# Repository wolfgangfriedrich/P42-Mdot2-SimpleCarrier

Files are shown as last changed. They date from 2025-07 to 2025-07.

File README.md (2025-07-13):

A carrier to connect to a M.2 2230/3030 or 2242/3042 Board through USB, UART or I2C. All other signals are broken out to to TH testpoints.

List of features:

    M.2 slot with all pads on the board to accept any key slot M.2 module, if the correct connector is mounted.
    Specifically made for A key and E key, targeting WiFi, Bluetooth, WWAN adapter.
    Works with a subset of signals for B key and M key, but not as a USB memory interface for SSDs.
    All signals available on through hole test points on a 2.54mm (0.1") grid.
    PCIe signals are routed as differential pairs.
    USB-C set up for 5V 3A max power draw.
    Switching regulator to generate 3.3V 1.5A to power the M.2 module.
    1.8V LDO regulator to be able to work with the 1.8V UART and I2C signals.
    Power switch for the 3.3V to the M.2 module with an enable jumper and 500mA over-current protection.
    LEDs for 1.8V, 3.3V and switched 3.3V; LED for over-current condition.
    4 mounting holes.
    Mounting holes for nuts to secure 2230 or 2242 modules.
    Level shifter and connector to make UART accessible on a 3-pin header.
    Level shifter and QWIIC connector to make I2C accessible on a 3-pin header.
    Extra testpoints for GND, VBUS, 3.3V, 1.8V
    Design in KiCAD.

The design came to life initially to test my M.2 RP2350 board (https://www.tindie.com/products/pier42/pico2-m2). I needed a test platform to access all signals of the M.2 interface with E or A key. Single Board Computers with a M.2 port often don't access all pins, so I built this board and think it is very useful.

M.2 carrier boards are generally for B or M key SSDs to other internal interfaces. I am not aware of any breakout board for M.2 modules with enhanced functionality. There are a few passive breakout boards available that simply connect all pins to standard headers.

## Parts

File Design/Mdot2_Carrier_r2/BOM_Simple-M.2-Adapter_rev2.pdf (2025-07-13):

# | Reference | Qty Value | Description | DNP JLCPCB # LCSC Part #Mfr | Mfr PN | Mfr1 | Mfr1 PN | Mfr2 | Mfr2 PN

1 | C1 | 1 10n | CAP CER 10NF 10% 50V X7R 0603 | C57112 | C57112 | generic | na | generic | na
2 | C2,C6,C10,C11 | 4 2.2u | CAP CER 2.2UF 16V X5R 0603 | C23630 | C23630 | generic | na | generic | na
3 | C3,C4 | 2 10u | CAP CER 10UF 50V X7R 1206 | C13585 | C13585 | Samsung CL31B106KBHNNNE | Samsung | CL31B106KBHNNNE
4 | C5,C9,C12,C13 | 4 100nF | Cap Cer, 100nF, +-10%, X7R, 50V, 0603 | C14663 | C14663 | generic | na | generic | na
5 | C7,C8 | 2 4.7u | CAP CER 4.7UF 50V X5R 0805 | C98192 | C98192 | Murata | GRT21BR61H475KE13L Samsung | CL21A475KBQNNNE | Murata | GRT21BR61H475KE13L
6 | D1,D3 | 2 Yellow | LED YELLOW CLEAR 0603 SMD | C434424 C434424 | WÃ¼rth | 150060YS75000 | Yongyu Photoelectric | SZYY0603Y
7 | D2 | 1 Green | LED GREEN CLEAR 0603 SMD | C434420 C434420 | WÃ¼rth | 150060GS75000 | Yongyu Photoelectric | SZYY0603G
8 | D4 | 1 Red | LED RED CLEAR 0603 SMD | C2286 | C2286 | | WÃ¼rth | 150060RS75000 | Hubei KENTO Elec | KT-0603R
9 | D5 | 1 DSS26 | TVS DIODE 12.8VWM 21.2VC SOD123 | C511867 C511867 On Semi | SS26FL | On Semi | SS26FL | BORN | DSS26
10 | FB1,FB2 | 2 600R/0.5A | IND FERRITE 600R 0.5A 0603 | C710380 C710380 Murata | BLM18AG601SN1D | Murata | BLM18AG601SN1D
11 | J1 | 1 Bus_M.2 | M.2 Socket 1-SD Mechanical Key AE | C2761457 FOXCONN AS0BC21-S48BE-7H | Amphenol ICC (FCI) MDT420E01001 | Amphenol ICC (FCI) | MDT420E03001
12 | J2 | 1 USB_C | CONN, USB-C 2.0, TH | C2988369 G-Switch GT-USB-7010ASV | G-Switch | GT-USB-7010ASV
13 | J3 | 1 ENABLE | CONN, 2PIN, 2.54MM, TH | C492401 C492401 Adam TechPH1-02-UA | Adam Tech | PH1-02-UA
14 | J4 | 1 QWIIC | CONN HEADER R/A 4POS 1MM SMD | C160404 C160404 JST | SH_SM04B-SRSS-TB | JST | SM04B-SRSS-TB(LF)(SN)
15 | J5 | 1 UART | CONN, 3PIN, 2.54MM, TH | C49257 | C49257 | Adam TechPH1-03-UA
16 | L1 | 1 4.7uH | FIXED IND 4.7UH 3A 37MOHM SMD | C171792 C171792 Murata | LQH5BPN4R7NT0L | Murata | LQH5BPN4R7NT0L | TDK | VLS6045AF-6R8M
17 | Q1 | 1 FDN304P | MOSFET P-CH 20V 2.4A 53mOhm, SOT23-3 | DNP | C154510 | ON Semi | FDN306P
18 | Q2 | 1 FDC6303N | MOSFET 2N-CH 25V 0.68A SOT23-6 G1S2G2D2S1D1 | C5246389 C5246389 Rohm | FDC6303N | TECH PUBLIC FDC6301N-TP
19 | R1,R7,R11 | 3 27R | RES 27R 1% 0.1W 0603 | C25190 | C25190 | generic | na | generic | na
20 | R2,R5,R6,R9,R10 | 5 5K1 | RES 5K1 1% 0.1W 0603 | C23186 | C23186 | generic | na | generic | na
21 | R3 | 1 15K4 | Res, 15K4, 1%, 0.1W, 0603 | C2933150 C2933150 generic | na | generic | na
22 | R4 | 1 47K0 | Res, 47K, 1%, 0.1W, 0603 | DNP C25819 | C25819 | generic | na | generic | na
23 | R8,R12,R13,R14,R15 | 5 47K0 | Res, 47K, 1%, 0.1W, 0603 | C25819 | C25819 | generic | na | generic | na
24 | U1 | 1 USBLC6-2 | DIODE, TVS, 2-CH 5V, SOT-666 | C2827693 C2827693 ST Micro USBLC6-2P6 | ST Micro | USBLC6-2P6 | TECH PUBLIC | USBLC6-2P6
25 | U2 | 1 TPS2041B | Single power-distribution switcher | C51386 | C51386 | TI | TPS2041BDBVR | TI | TPS2041BDBVT
26 | U3 | 1 AP2125KS-1.8 IC REG LINEAR 1.8V 300MA SOT23-5 | C7214645 C7214645 Diodes Inc.AP2125KS-1.8TRG1 | Diodes Inc. | AP2125KS-1.8TRG1
27 | U4 | 1 AP3211 | IC SWITCHER 4V TO 21V 1A SOT23-6 | C154863 C154863 Diodes Inc AP3211KTR-G1 | Diodes Inc | AP3211KTR-G1 | Rohm | BD9G101G-TR (different FB resistors)
28 | U5 | 1 TXS0102DCT | IC, Level Shifter 2-bit, 1.6V to 5.5V, SSOP-8 | C324082 C324082 TI | TXS0102DCTR

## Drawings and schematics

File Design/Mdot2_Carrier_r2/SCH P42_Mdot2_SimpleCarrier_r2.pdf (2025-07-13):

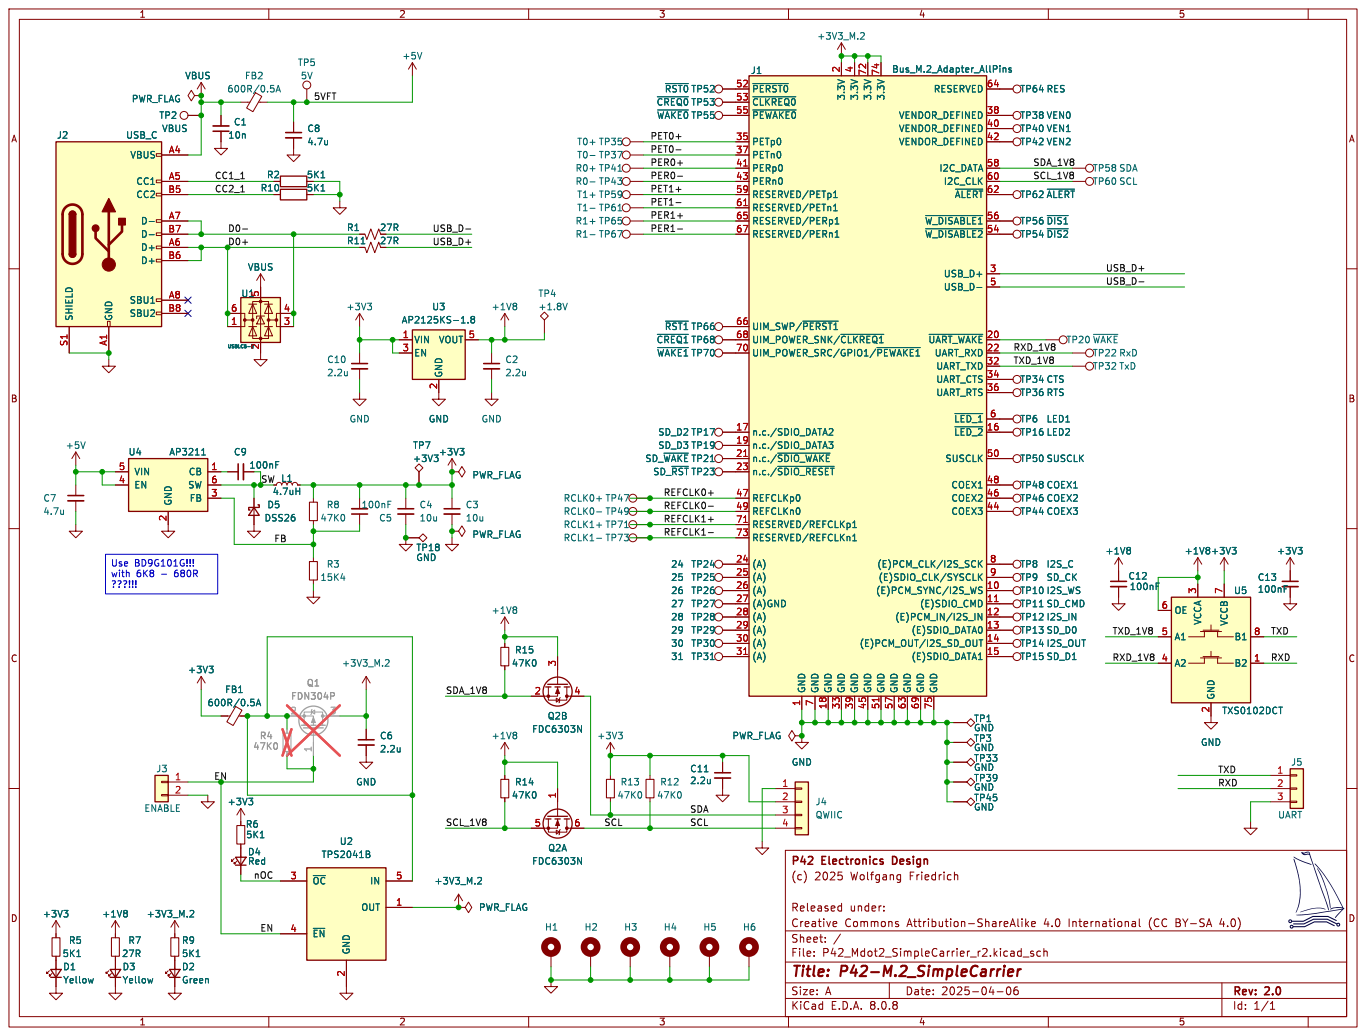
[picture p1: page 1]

7 UIM_POWER_SRC/GPIO1/~{PEWAKE1} 70 RESERVED/REFCLKp1 71 3.3V 72 RESERVED/REFCLKn1 73 3.3V 74 GND 75 TP34 CTS

4 VENDOR_DEFINED 40 PERp0 41 VENDOR_DEFINED 42 PERn0 43 COEX3 44 GND 45 COEX2 46 REFCLKp0 47 COEX1 48 REFCLKn0 49 USB_D- 5 SUSCLK 50 GND 51 ~{PERST0} 52 ~{CLKREQ0} 53 ~{W_DISABLE2}54 ~{PEWAKE0} 55 ~{W_DISABLE1}56 GND 57

2 FB 3 EN 4 VIN 5 SW 6 U4 AP3211 TP54 ~{DIS2} TP56 ~{DIS1} TP62 ~{ALERT} TP58 SDA

2 FB 3 EN 4 VIN 5 SW 6 D1Yellow

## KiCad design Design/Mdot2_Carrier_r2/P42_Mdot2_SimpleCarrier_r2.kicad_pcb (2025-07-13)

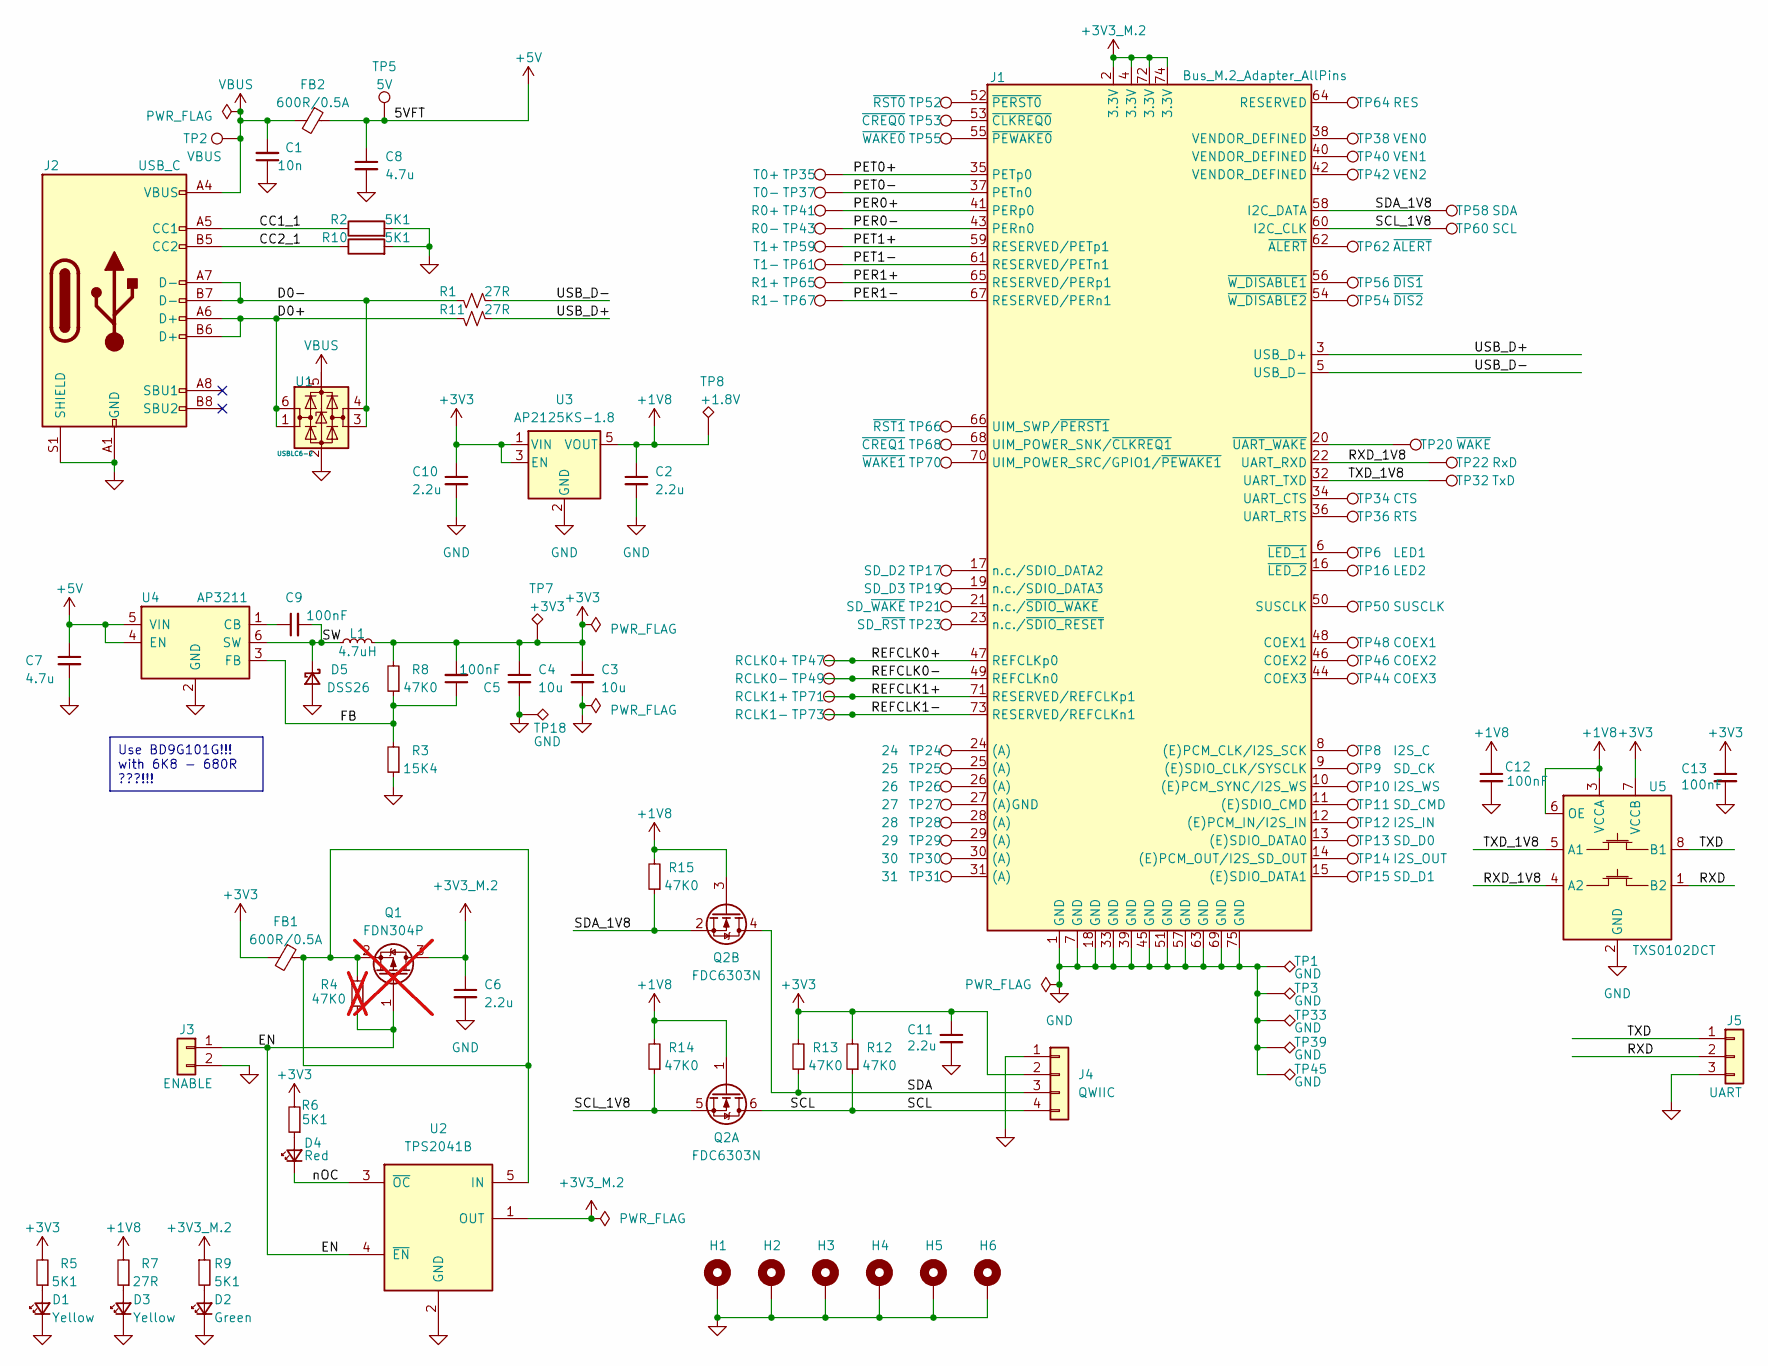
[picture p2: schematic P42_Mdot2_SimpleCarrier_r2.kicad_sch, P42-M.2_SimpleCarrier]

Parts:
C1: 10n; C_0603_1608Metric; Mfr PN na; JLCPCB # C57112
C2, C6, C10, C11: 2.2u; C_0603_1608Metric; Mfr PN na; JLCPCB # C23630
C3, C4: 10u; C_1206_3216Metric; Mfr PN CL31B106KBHNNNE; JLCPCB # C13585
C5, C12, C13: 100nF; C_0603_1608Metric; Mfr PN na; JLCPCB # C14663
C7, C8: 4.7u; C_0805_2012Metric; Mfr PN GRT21BR61H475KE13L; JLCPCB # C98192
C9: 100nF; C_0603_1608Metric; Mfr1 PN na; JLCPCB # C14663
D1, D3: Yellow; LED_0603_1608Metric; Mfr1 PN 150060YS75000; JLCPCB # C434424
D2: Green; LED_0603_1608Metric; Mfr1 PN 150060GS75000; JLCPCB # C434420
D4: Red; LED_0603_1608Metric; Mfr1 PN 150060RS75000; JLCPCB # C2286
D5: DSS26; D_SOD-123; Mfr PN SS26FL; JLCPCB # C511867
FB1, FB2: 600R/0.5A; L_0603_1608Metric; Mfr PN BLM18AG601SN1D; JLCPCB # C710380
H1, H2, H3, H4, H5, H6: MountingHole_Pad; MountingHole_3.2mm_M3_Pad_Via
J1: Bus_M.2_Adapter_AllPins; NGFF_M.2_AE-Key_AMP_MDT420; Mfr1 PN MDT420E01001; LCSC Part # C2761457
J2: USB_C; USB_C_Receptacle_G-Switch_GT-USB-7010ASV; Mfr PN GT-USB-7010ASV; LCSC Part # C2988369
J3: ENABLE; PinHeader_1x02_P2.54mm_Vertical; Mfr PN PH1-02-UA; JLCPCB # C492401
J4: QWIIC; JST_SH_SM04B-SRSS-TB_1x04-1MP_P1.00mm_Horizontal; Mfr1 PN SM04B-SRSS-TB(LF)(SN); JLCPCB # C160404
J5: UART; PinHeader_1x03_P2.54mm_Vertical; Mfr PN PH1-03-UA; JLCPCB # C49257
L1: 4.7uH; L_Bourns_SRN6045TA; Mfr2 PN VLS6045AF-6R8M; JLCPCB # C171792
Q1: FDN304P; SOT-23-3; Mfr1 PN FDN306P; LCSC Part # C154510; not fitted
Q2: FDC6303N; SOT-23-6; Mfr PN FDC6303N; JLCPCB # C5246389
R1, R7, R11: 27R; R_0603_1608Metric; Mfr PN na; JLCPCB # C25190
R2, R5, R6, R9, R10: 5K1; R_0603_1608Metric; Mfr PN na; JLCPCB # C23186
R3: 15K4; R_0603_1608Metric; Mfr PN na; JLCPCB # C2933150
R4: 47K0; R_0603_1608Metric; Mfr PN na; JLCPCB # C25819; not fitted
R8, R12, R13, R14, R15: 47K0; R_0603_1608Metric; Mfr PN na; JLCPCB # C25819
TP1, TP3, TP18, TP33, TP39, TP45: GND; THTPad_D1.5mm_Drill1.0mm
TP2: VBUS; THTPad_D1.5mm_Drill1.0mm
TP5: 5V; THTPad_D1.5mm_Drill1.0mm
TP6: LED1; THTPad_D1.5mm_Drill1.0mm
TP7: +3V3; THTPad_D1.5mm_Drill1.0mm
TP8: I2S_C; THTPad_D1.5mm_Drill1.0mm
TP9: SD_CK; THTPad_D1.5mm_Drill1.0mm
TP10: I2S_WS; THTPad_D1.5mm_Drill1.0mm
TP11: SD_CMD; THTPad_D1.5mm_Drill1.0mm
TP12: I2S_IN; THTPad_D1.5mm_Drill1.0mm
TP13: SD_D0; THTPad_D1.5mm_Drill1.0mm
TP14: I2S_OUT; THTPad_D1.5mm_Drill1.0mm
TP15: SD_D1; THTPad_D1.5mm_Drill1.0mm
TP16: LED2; THTPad_D1.5mm_Drill1.0mm
TP17: SD_D2; THTPad_D1.5mm_Drill1.0mm
TP19: SD_D3; THTPad_D1.5mm_Drill1.0mm
TP20: ~{WAKE}; THTPad_D1.5mm_Drill1.0mm
TP21: SD_~{WAKE}; THTPad_D1.5mm_Drill1.0mm
TP22: RxD; THTPad_D1.5mm_Drill1.0mm
TP23: SD_~{RST}; THTPad_D1.5mm_Drill1.0mm
TP24: 24; THTPad_D1.5mm_Drill1.0mm
TP25: 25; THTPad_D1.5mm_Drill1.0mm
TP26: 26; THTPad_D1.5mm_Drill1.0mm
TP27: 27; THTPad_D1.5mm_Drill1.0mm
TP28: 28; THTPad_D1.5mm_Drill1.0mm
TP29: 29; THTPad_D1.5mm_Drill1.0mm
TP30: 30; THTPad_D1.5mm_Drill1.0mm
TP31: 31; THTPad_D1.5mm_Drill1.0mm
TP32: TxD; THTPad_D1.5mm_Drill1.0mm
TP34: CTS; THTPad_D1.5mm_Drill1.0mm
TP35: T0+; THTPad_D1.5mm_Drill1.0mm
TP36: RTS; THTPad_D1.5mm_Drill1.0mm
TP37: T0-; THTPad_D1.5mm_Drill1.0mm
TP38: VEN0; THTPad_D1.5mm_Drill1.0mm
TP40: VEN1; THTPad_D1.5mm_Drill1.0mm
TP41: R0+; THTPad_D1.5mm_Drill1.0mm
TP42: VEN2; THTPad_D1.5mm_Drill1.0mm
TP43: R0-; THTPad_D1.5mm_Drill1.0mm
TP44: COEX3; THTPad_D1.5mm_Drill1.0mm
TP46: COEX2; THTPad_D1.5mm_Drill1.0mm
TP47: RCLK0+; THTPad_D1.5mm_Drill1.0mm
TP48: COEX1; THTPad_D1.5mm_Drill1.0mm
TP49: RCLK0-; THTPad_D1.5mm_Drill1.0mm
TP50: SUSCLK; THTPad_D1.5mm_Drill1.0mm
TP52: ~{RST0}; THTPad_D1.5mm_Drill1.0mm
TP53: ~{CREQ0}; THTPad_D1.5mm_Drill1.0mm
TP54: ~{DIS2}; THTPad_D1.5mm_Drill1.0mm
TP55: ~{WAKE0}; THTPad_D1.5mm_Drill1.0mm
TP56: ~{DIS1}; THTPad_D1.5mm_Drill1.0mm
TP58: SDA; THTPad_D1.5mm_Drill1.0mm
TP59: T1+; THTPad_D1.5mm_Drill1.0mm
TP60: SCL; THTPad_D1.5mm_Drill1.0mm
TP61: T1-; THTPad_D1.5mm_Drill1.0mm
TP62: ~{ALERT}; THTPad_D1.5mm_Drill1.0mm
TP64: RES; THTPad_D1.5mm_Drill1.0mm
TP65: R1+; THTPad_D1.5mm_Drill1.0mm
TP66: ~{RST1}; THTPad_D1.5mm_Drill1.0mm
TP67: R1-; THTPad_D1.5mm_Drill1.0mm
TP68: ~{CREQ1}; THTPad_D1.5mm_Drill1.0mm
TP70: ~{WAKE1}; THTPad_D1.5mm_Drill1.0mm
TP71: RCLK1+; THTPad_D1.5mm_Drill1.0mm
TP73: RCLK1-; THTPad_D1.5mm_Drill1.0mm
U1: USBLC6-2; SOT-666; Mfr PN USBLC6-2P6; JLCPCB # C2827693
U2: TPS2041B; SOT-23-5; Mfr PN TPS2041BDBVR; JLCPCB # C51386
U3: AP2125KS-1.8; SOT-23-5; Mfr PN AP2125KS-1.8TRG1; JLCPCB # C7214645
U4: AP3211; SOT-23-6; Mfr3 PN AP64060WU-7 (6.8uH, 69.8K, 22.1K); JLCPCB # C154863
U5: TXS0102DCT; SSOP-8_2.95x2.8mm_P0.65mm; Mfr PN TXS0102DCTR; JLCPCB # C324082

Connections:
+3V3: C3.1, C4.1, C5.2, C10.1, C11.1, C13.1, FB1.2, J4.2, L1.2, R5.2, R6.2, R8.2, R12.2, R13.2, TP7.1, U3.1 (VIN), U3.3 (EN), U5.7 (VCCB)
+3V3_M.2: C6.1, J1.2 (3.3V), J1.4 (3.3V), J1.72 (3.3V), J1.74 (3.3V), Q1.3 (D), R9.1, U2.1 (OUT)
+5V: C7.1, C8.1, FB2.1, TP5.1, U4.4 (EN), U4.5 (VIN)
/CC1_1: J2.A5 (CC1), R2.1
/CC2_1: J2.B5 (CC2), R10.1
/D0+: J2.A6 (D+), J2.B6 (D+), R11.2, U1.1 (I/O1), U1.6 (I/O1)
/D0-: J2.A7 (D-), J2.B7 (D-), R1.2, U1.3 (I/O2), U1.4 (I/O2)
/EN: J3.1, Q1.1 (G), R4.1, U2.4 (~EN)
/FB: C5.1, R3.2, R8.1, U4.3 (FB)
/PER0+: J1.41 (PERp0), TP41.1
/PER0-: J1.43 (PERn0), TP43.1
/PER1+: J1.65 (RESERVED/PERp1), TP65.1
/PER1-: J1.67 (RESERVED/PERn1), TP67.1
/PET0+: J1.35 (PETp0), TP35.1
/PET0-: J1.37 (PETn0), TP37.1
/PET1+: J1.59 (RESERVED/PETp1), TP59.1
/PET1-: J1.61 (RESERVED/PETn1), TP61.1
/REFCLK0+: J1.47 (REFCLKp0), TP47.1
/REFCLK0-: J1.49 (REFCLKn0), TP49.1
/REFCLK1+: J1.71 (RESERVED/REFCLKp1), TP71.1
/REFCLK1-: J1.73 (RESERVED/REFCLKn1), TP73.1
/RXD: J5.2, U5.1 (B2)
/RXD_1V8: J1.22 (UART_RXD), TP22.1, U5.4 (A2)
/SCL: J4.4, Q2.6 (D), R12.1
/SCL_1V8: J1.60 (I2C_CLK), Q2.5 (S), R14.1, TP60.1
/SDA: J4.3, Q2.4 (D), R13.1
/SDA_1V8: J1.58 (I2C_DATA), Q2.2 (S), R15.1, TP58.1
/SW: C9.2, D5.1 (K), L1.1, U4.6 (SW)
/TXD: J5.1, U5.8 (B1)
/TXD_1V8: J1.32 (UART_TXD), TP32.1, U5.5 (A1)
/USB_D+: J1.3 (USB_D+), R11.1
/USB_D-: J1.5 (USB_D-), R1.1
/nOC: D4.1 (K), U2.3 (~OC)
GND: C1.1, C2.2, C3.2, C4.2, C6.2, C7.2, C8.2, C10.2, C11.2, C12.2, C13.2, D1.1 (K), D2.1 (K), D3.1 (K), D5.2 (A), H1.1, H2.1, H3.1, H4.1, H5.1, H6.1, J1.1 (GND), J1.7 (GND), J1.18 (GND), J1.33 (GND), J1.39 (GND), J1.45 (GND), J1.51 (GND), J1.57 (GND), J1.63 (GND), J1.69 (GND), J1.75 (GND), J2.A1 (GND), J2.A12 (GND), J2.B1 (GND), J2.B12 (GND), J2.S1 (SHIELD), J3.2, J4.1, J5.3, R2.2, R3.1, R10.2, TP1.1, TP3.1, TP18.1, TP33.1, TP39.1, TP45.1, U1.2 (GND), U2.2 (GND), U3.2 (GND), U4.2 (GND), U5.2 (GND)
unnamed: D1.2 (A), R5.1
unnamed: D2.2 (A), R9.2
unnamed: D3.2 (A), R7.1
unnamed: D4.2 (A), R6.1
unnamed: J1.24 ((A)), TP24.1
unnamed: J1.25 ((A)), TP25.1
unnamed: J1.26 ((A)), TP26.1
unnamed: J1.28 ((A)), TP28.1
unnamed: J1.29 ((A)), TP29.1
unnamed: J1.30 ((A)), TP30.1
unnamed: J1.31 ((A)), TP31.1
unnamed: J1.27 ((A)GND), TP27.1
unnamed: J1.12 ((E)PCM_IN/I2S_IN), TP12.1
unnamed: J1.14 ((E)PCM_OUT/I2S_SD_OUT), TP14.1
unnamed: J1.10 ((E)PCM_SYNC/I2S_WS), TP10.1
unnamed: J1.9 ((E)SDIO_CLK/SYSCLK), TP9.1
unnamed: J1.11 ((E)SDIO_CMD), TP11.1
unnamed: J1.13 ((E)SDIO_DATA0), TP13.1
unnamed: J1.15 ((E)SDIO_DATA1), TP15.1
unnamed: J1.48 (COEX1), TP48.1
unnamed: J1.46 (COEX2), TP46.1
unnamed: J1.44 (COEX3), TP44.1
unnamed: J1.64 (RESERVED), TP64.1
unnamed: J1.50 (SUSCLK), TP50.1
unnamed: J1.34 (UART_CTS), TP34.1
unnamed: J1.36 (UART_RTS), TP36.1
unnamed: J1.68 (UIM_POWER_SNK/~CLKREQ1), TP68.1
unnamed: J1.70 (UIM_POWER_SRC/GPIO1/~PEWAKE1), TP70.1
unnamed: J1.66 (UIM_SWP/~PERST1), TP66.1
unnamed: J1.38 (VENDOR_DEFINED), TP38.1
unnamed: J1.40 (VENDOR_DEFINED), TP40.1
unnamed: J1.42 (VENDOR_DEFINED), TP42.1
unnamed: J1.17 (n.c./SDIO_DATA2), TP17.1
unnamed: J1.19 (n.c./SDIO_DATA3), TP19.1
unnamed: J1.23 (n.c./~SDIO_RESET), TP23.1
unnamed: J1.21 (n.c./~SDIO_WAKE), TP21.1
unnamed: J1.62 (~ALERT), TP62.1
unnamed: J1.53 (~CLKREQ0), TP53.1
unnamed: J1.6 (~LED_1), TP6.1
unnamed: J1.16 (~LED_2), TP16.1
unnamed: J1.52 (~PERST0), TP52.1
unnamed: J1.55 (~PEWAKE0), TP55.1
unnamed: J1.20 (~UART_WAKE), TP20.1
unnamed: J1.56 (~W_DISABLE1), TP56.1
unnamed: J1.54 (~W_DISABLE2), TP54.1
unnamed: FB1.1, Q1.2 (S), R4.2, U2.5 (IN)
unnamed: C9.1, U4.1 (CB)
VBUS: C1.2, FB2.2, J2.A4 (VBUS), J2.A9 (VBUS), J2.B4 (VBUS), J2.B9 (VBUS), TP2.1, U1.5 (VBUS)

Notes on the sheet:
Use BD9G101G!!! with 6K8 - 680R ???!!!

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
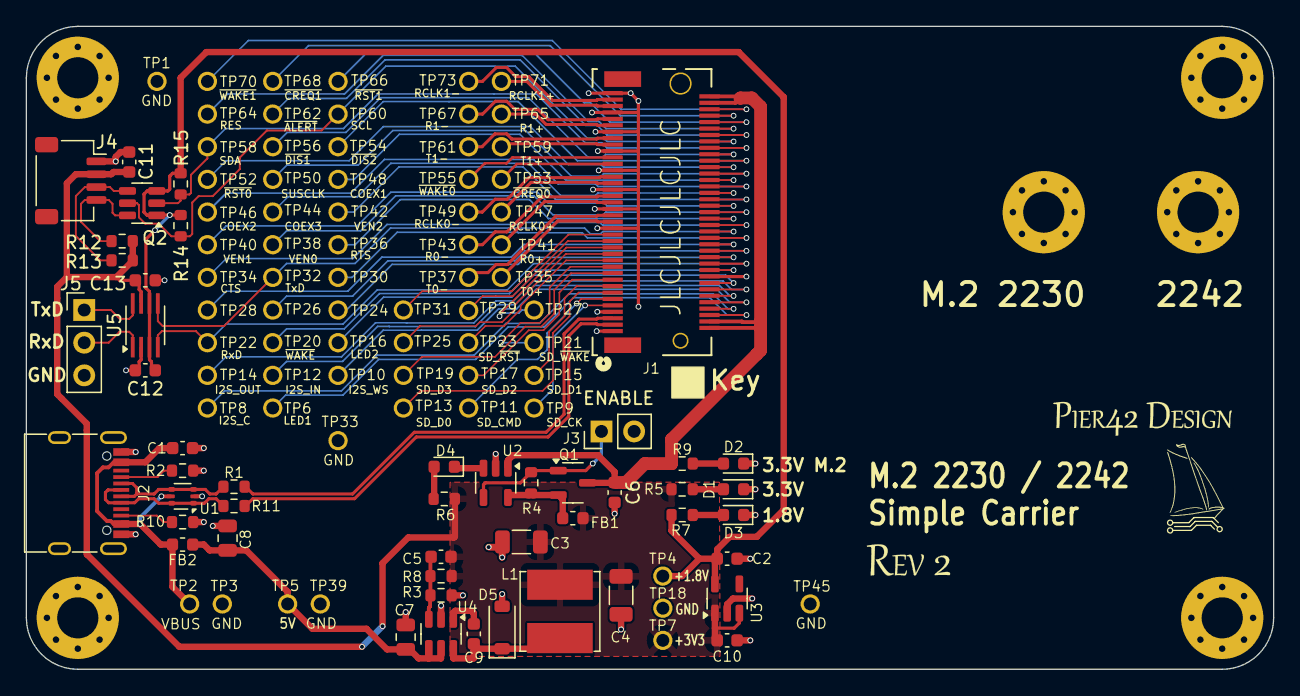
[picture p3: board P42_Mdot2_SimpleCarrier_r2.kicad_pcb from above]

Board: 2 copper layers, 97.0 x 50.0 mm, 122 parts (0 on the bottom side), 84 nets.

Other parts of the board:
TP4: +1.8V; THTPad_D1.5mm_Drill1.0mm

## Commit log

2025-07-13 Initial upload
    Initial design files
    [P42_Mdot2_SimpleCarrier_r2.kicad_pcb, P42_Mdot2_SimpleCarrier_r2.kicad_sch]
2025-07-13 Create BOM_Simple-M.2-Adapter_rev2.pdf
    Added BOM pdf

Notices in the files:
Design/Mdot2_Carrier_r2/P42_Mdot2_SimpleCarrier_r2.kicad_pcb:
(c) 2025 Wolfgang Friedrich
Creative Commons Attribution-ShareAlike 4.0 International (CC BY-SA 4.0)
